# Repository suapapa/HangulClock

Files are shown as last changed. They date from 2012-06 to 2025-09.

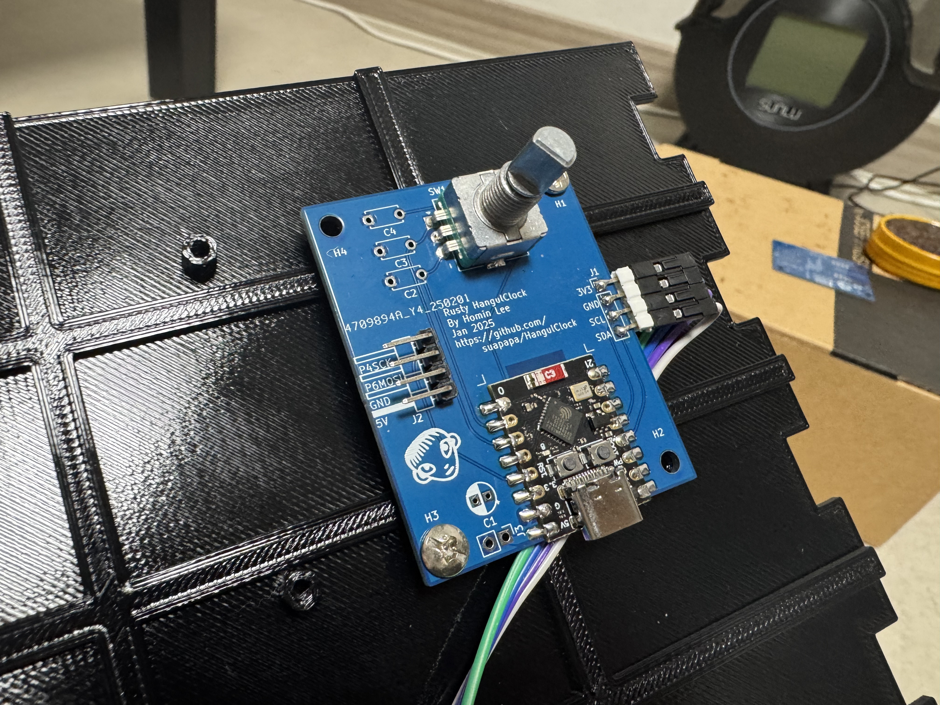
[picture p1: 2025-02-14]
rusty_hangulclock/photo/IMG_3785.jpg

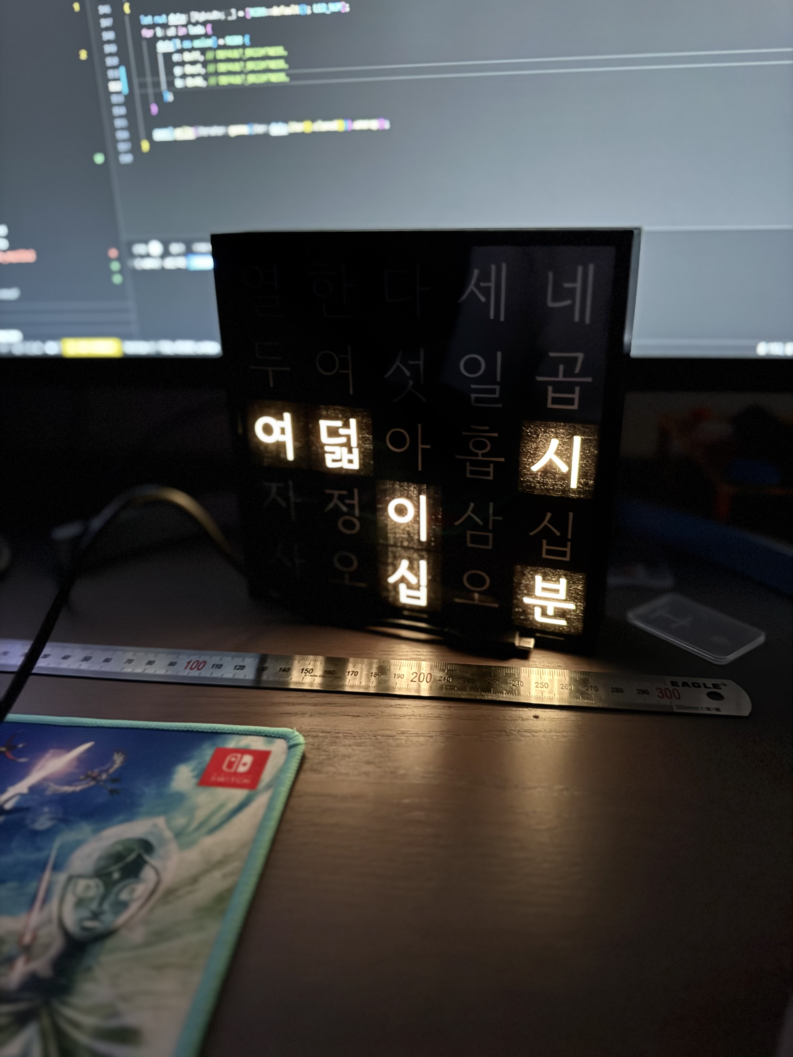
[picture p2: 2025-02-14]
rusty_hangulclock/photo/IMG_3756.jpg

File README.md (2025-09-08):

# 한글시계 - HangulClock

HangulClock

한글시계는 오픈소스(SW/HW) 입니다. [시연 동영상](https://youtu.be/ApymC7qAVTI)

- Make Korea의 2011 컨테스트 수상 작 (1등 없는 2등)
- [A Word Clock by drj113](http://www.instructables.com/id/A-Word-Clock/)에서 영감을 얻었습니다.

## 소스코드

### Rusty HangulClock

~~Please Refer [rusty_hangulclock/README.md](rusty_hangulclock/README.md)~~

> ⚠️ Moved to seperated repository [suapapa/rusty-hangulclock](https://github.com/suapapa/rusty-hangulclock)

### Go program which using Periph.io

Build for ARM64 SBCs:

    $ cd go_hangulclock
    $ GOARCH=arm64 GOOS=linux go build

Then, install binary and system service config by reference `deploy.sh`

### Arduino Sketch (prototype)

Need update submoduls HT1380 and LedControl to build the sketch;

    $ git submodule update

## 링크

- 블로그 글:
  - [다시만든 한글시계 with 러스트](https://homin.dev/blog/post/20241222_rusty_hangulclock/) - 2024-12
  - [11년 만에 완성한, 원조, 한글시계](https://homin.dev/blog/post/20221009_hangulclock_is_re-written_in_golang/) - 2022-09
  - [한글시계 뒷 이야기](https://homin.dev/blog/p=493/) - 2011-11

## 라이선스

### 5x5 한글 조합 - BY-CC

<br />이 저작물은 <a rel="license" href="http://creativecommons.org/licenses/by/4.0/">크리에이티브 커먼즈 저작자표시 4.0 국제 라이선스</a>에 따라 이용할 수 있습니다.

### 소스코드 - OpenSource

아두이노 스케치와, 고 프로그램의 라이선스가 각각 다릅니다. 각각의 폴더에서 확인하세요.
- Rust program: [rusty_hangulclock/LICENSE](rusty_hangulclock/LICENSE) - BSD
- Go program: [go_hangulclock/LICENSE](go_hangulclock/LICENSE) - BSD
- Arduino Sketch: [ardino/HangulClock/LICENSE](arduino/HangulClock/LICENSE) - GPL

### 회로도, 아트워크, 케이스 및 그 밖의 파일들 - Proprietary

회로도, 아트워크, 케이스 설계 파일 및 그 밖의 모든 파일들은 독점 라이선스 하에 있습니다. 
이러한 파일들의 사용, 복제, 수정, 배포는 저작권자의 명시적 허가 없이는 금지됩니다.

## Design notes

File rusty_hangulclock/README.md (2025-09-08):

# Rusty HangulClock

rusty_hangulclock

HangulClock written in Rust on ESP32C3 board

Hardware:
- [sch & pcb artwork](../sch/rusty-hangulclock/) - a KiCad project
- [case 3d model](../case/)

## Build and flash

### Pre requirement
Install toolchain (only for one time):
```sh
cargo install espup cargo-espflash ldproxy
espup install
```

### Build and flash:
For dotstar:
```sh
make flash_dotstar
```

For neopixel:
```sh
make flash_neopixel
```

### Factory reset settings:
```sh
make erase_nvs
```

## TODOs
- [x] Display color setting
- [x] Timezone setting
- [x] WPS to connect Wifi
- [x] NTP to sync time

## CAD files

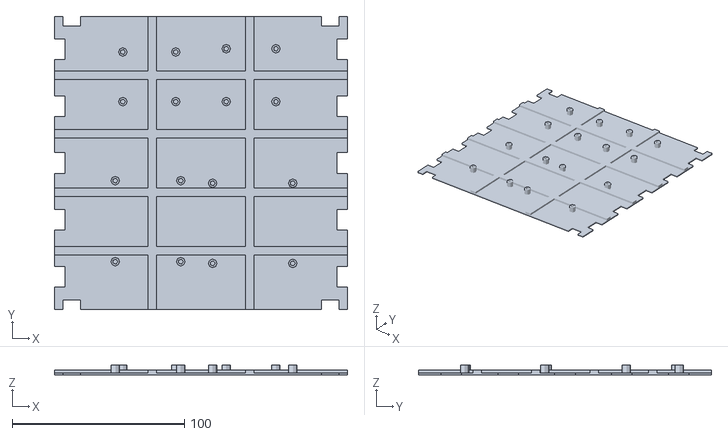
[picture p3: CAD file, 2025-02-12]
case/hangulclock_light_pannel.stl
170.0 x 170.0 x 5.60

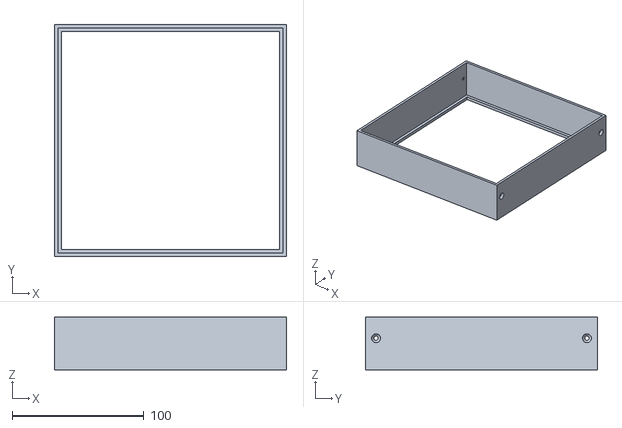
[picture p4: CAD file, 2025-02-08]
case/hangulclock_case.stl
176.0 x 176.0 x 40.0

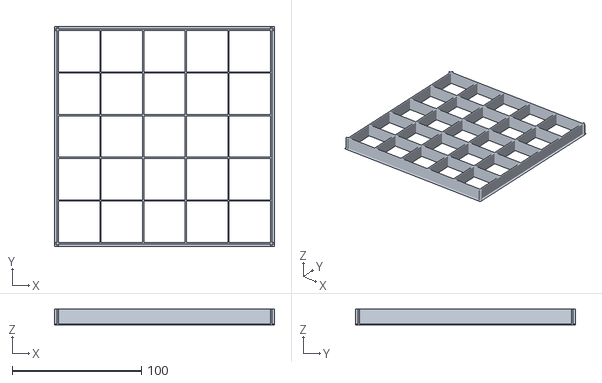
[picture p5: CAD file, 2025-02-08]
case/hangulclock_light_tunnel.stl
170.0 x 170.0 x 12.0

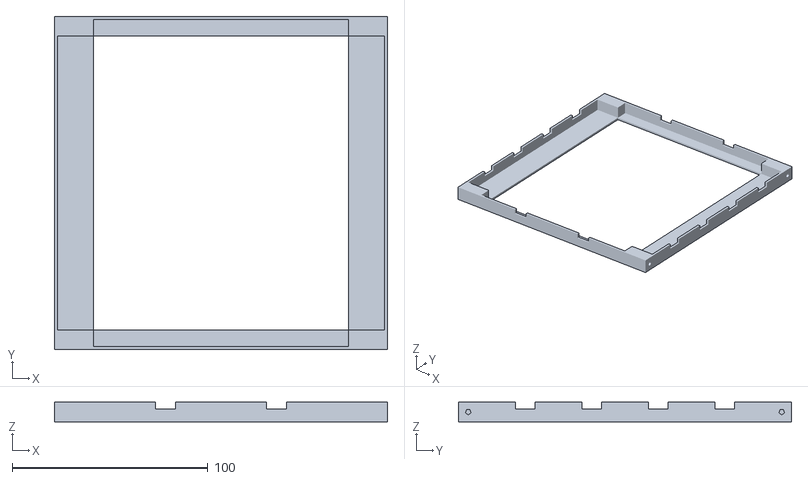
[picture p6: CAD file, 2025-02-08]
case/hangulclock_case_back.stl
170.0 x 170.0 x 10.0

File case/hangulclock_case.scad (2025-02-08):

difference() {
    translate([0,0,40/2])
        difference() {
            cube([176,176,40], center=true);
            cube([165,165,70], center=true);
            translate([0,0,3]) cube([171,171,40], center=true);
            //translate([2.5,2.5,2.5]) cube([170,170,70]);
            
        }

    translate([-170/2,170/2-5,24])
        rotate([0,90,0]) screw_hole();
    translate([-170/2,-170/2+5,24])
        rotate([0,90,0]) screw_hole();
    translate([170/2,170/2-5,24])
        rotate([0,-90,0]) screw_hole();
    translate([170/2,-170/2+5,24])
        rotate([0,-90,0]) screw_hole();
}



module screw_hole() {
    translate([0,0,-3])
    union() {
        translate([0,0,5]) cylinder(10, 1.5+0.1, 1.5+0.1, center=true, $fn=20);
        translate([0,0,2.5/2-0.2]) cylinder(2.5+0.1,3.5+0.1,1.5, center=true, $fn=20);
    }
}

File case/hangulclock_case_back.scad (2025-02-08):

difference() {
    cube([170,170,10], center=true);
    translate([0,0,1.6]) cube([170-1.6*2,150,10], center=true);
    translate([0,0,1.6]) cube([130,170-1.6*2,10], center=true);
    translate([0,0,0]) cube([130,150,15], center=true);
    
    translate([0,17,4]) cube([171,10,5], center=true);
    translate([0,17+34,4]) cube([171,10,5], center=true);
    translate([0,-17,4]) cube([171,10,5], center=true);
    translate([0,-17-34,4]) cube([171,10,5], center=true);
    translate([170/6,0,4]) cube([10,171,5], center=true);
    translate([-170/6,0,4]) cube([10,171,5], center=true);
    
    translate([-170/2,170/2-5,0])
        rotate([0,90,0]) cylinder(h=20,r=1.5,center=true);
    translate([-170/2,-170/2+5,0])
        rotate([0,90,0]) cylinder(h=20,r=1.5,center=true);
    translate([170/2,170/2-5,0])
        rotate([0,90,0]) cylinder(h=20,r=1.5,center=true);
    translate([170/2,-170/2+5,0])
        rotate([0,90,0]) cylinder(h=20,r=1.5,center=true);
}

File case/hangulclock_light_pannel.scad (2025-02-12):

difference() {
    union() {
        translate([-30,50,0]) oled_supports();
        translate([30,50,0]) oled_supports_v();
        translate([-30,-35,0]) board_supports();
        translate([30,-35,0]) board_supports_2();
        cube([170, 170, 1.2], center=true);
        translate([-170/6,0,1]) cube([5,170, 2.5], center=true);
        translate([+170/6,0,1]) cube([5,170, 2.5], center=true);
        translate([0,17,1]) cube([170, 5, 2.5], center=true);
        translate([0,17+34,1]) cube([170, 5, 2.5], center=true);
        translate([0,-17,1]) cube([170, 5, 2.5], center=true);
        translate([0,-17-34,1]) cube([170, 5, 2.5], center=true);
    }
    translate([-170/2,0,-1]) cube([12,12,15], center=true);
    translate([170/2,0,-1]) cube([12,12,15], center=true);
    translate([-170/2,33,-1]) cube([12,12,15], center=true);
    translate([170/2,33,-1]) cube([12,12,15], center=true);
    translate([-170/2,-33,-1]) cube([12,12,15], center=true);
    translate([170/2,-33,-1]) cube([12,12,15], center=true);    
    translate([-170/2,33*2,-1]) cube([12,12,15], center=true);
    translate([170/2,33*2,-1]) cube([12,12,15], center=true);
    translate([-170/2,-33*2,-1]) cube([12,12,15], center=true);
    translate([170/2,-33*2,-1]) cube([12,12,15], center=true);
    
    translate([75,82.5,0]) cube([10,6,2], center=true);
    translate([-75,82.5,0]) cube([10,6,2], center=true);
    translate([75,-82.5,0]) cube([10,6,2], center=true);
    translate([-75,-82.5,0]) cube([10,6,2], center=true);
}

module oled_supports() {
    translate([-(33.7-3)/2,-(31.8-3)/2]) {
        support(3, 5);
        translate([33.7-3,0,0]) support(3, 5);
        translate([0,31.8-3,0]) support(3, 5);
        translate([33.7-3,31.8-3,0]) support(3, 5);
    }
}

module oled_supports_v() {
    translate([-(33.7-3)/2,-(31.8-3)/2]) {
        support(3, 5);
        translate([0,33.7-3,0]) support(3, 5);
        translate([31.8-3,0,0]) support(3, 5);
        translate([31.8-3,33.7-3,0]) support(3, 5);
    }
}

// for pcb rev2 and rev3
module board_supports() {
    translate([-(41.5-2)/2,-(46.5-2)/2]) {
        support(3, 5);
        translate([38,0,0]) support(3, 5);
        translate([0,47,0]) support(3, 5);
        translate([38,47,0]) support(3, 5);
    }
}

// for pcb rev1
module board_supports_2() {
    translate([-(46.5)/2,-(46.5)/2]) {
        support(3, 5);
        translate([46.5,0,0]) support(3, 5);
        translate([0,46.5,0]) support(3, 5);
        translate([46.5,46.5,0]) support(3, 5);
    }
}

module support(in, h) {
    translate([0,0,h/2]) difference() {
        cylinder(h, in/2+1,in/2+1, center=true);
        translate([0,0,-1]) cylinder(h+2, in/2, in/2, center=true);
    }
}

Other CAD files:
case/hangulclock_light_tunnel.scad
case/spring.scad

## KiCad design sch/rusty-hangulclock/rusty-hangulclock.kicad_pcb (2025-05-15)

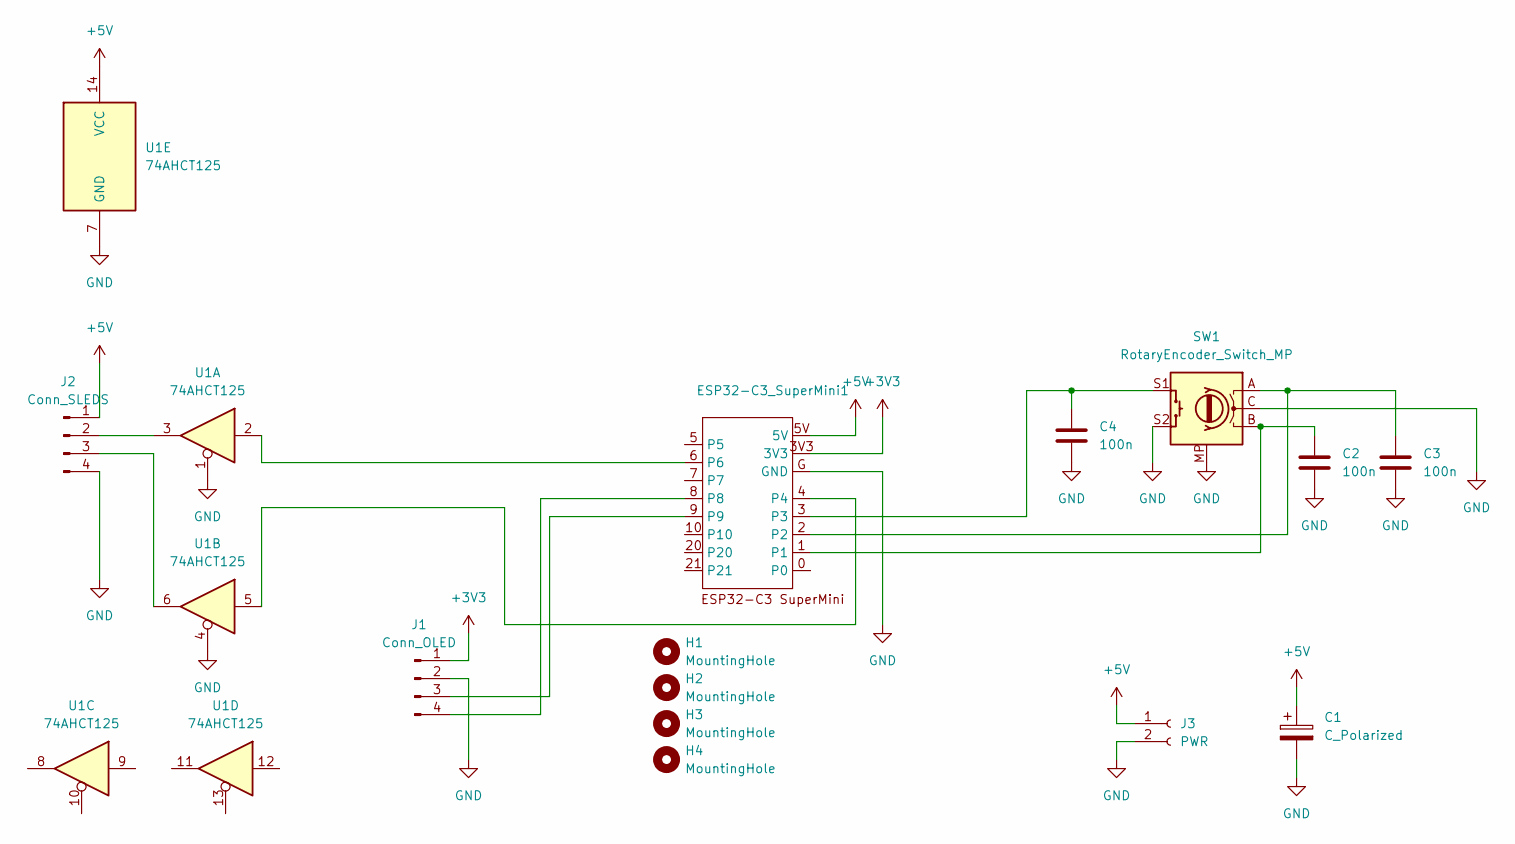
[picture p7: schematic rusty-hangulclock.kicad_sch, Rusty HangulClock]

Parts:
C1: C_Polarized; CP_Radial_D4.0mm_P2.00mm
C2, C3, C4: 100n; C_Disc_D5.0mm_W2.5mm_P5.00mm
ESP32-C3_SuperMini1: ESP32-C3_SuperMini_SMD
H1, H2, H3, H4: MountingHole; MountingHole_3.2mm_M3
J1: Conn_OLED; PinHeader_1x04_P2.54mm_Vertical
J2: Conn_SLEDS; PinHeader_1x04_P2.54mm_Horizontal
J3: PWR; PinHeader_1x02_P2.54mm_Vertical
SW1: RotaryEncoder_Switch_MP; RotaryEncoder_Alps_EC11E-Switch_Vertical_H20mm
U1: 74AHCT125; SOIC-14_3.9x8.7mm_P1.27mm

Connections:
+3V3: ESP32-C3_SuperMini1.3V3, J1.1
+5V: C1.1, ESP32-C3_SuperMini1.5V, J2.1, J3.1, U1.14 (VCC)
GND: C1.2, C2.2, C3.2, C4.2, ESP32-C3_SuperMini1.G (GND), J1.2, J2.4, J3.2, SW1.C, SW1.MP, SW1.S2, U1.1, U1.4, U1.7 (GND)
unnamed: C2.1, ESP32-C3_SuperMini1.1, SW1.B
unnamed: C3.1, ESP32-C3_SuperMini1.2, SW1.A
unnamed: C4.1, ESP32-C3_SuperMini1.3, SW1.S1
unnamed: ESP32-C3_SuperMini1.4, U1.5
unnamed: ESP32-C3_SuperMini1.6, U1.2
unnamed: ESP32-C3_SuperMini1.8, J1.4
unnamed: ESP32-C3_SuperMini1.9, J1.3
unnamed: J2.2, U1.3
unnamed: J2.3, U1.6

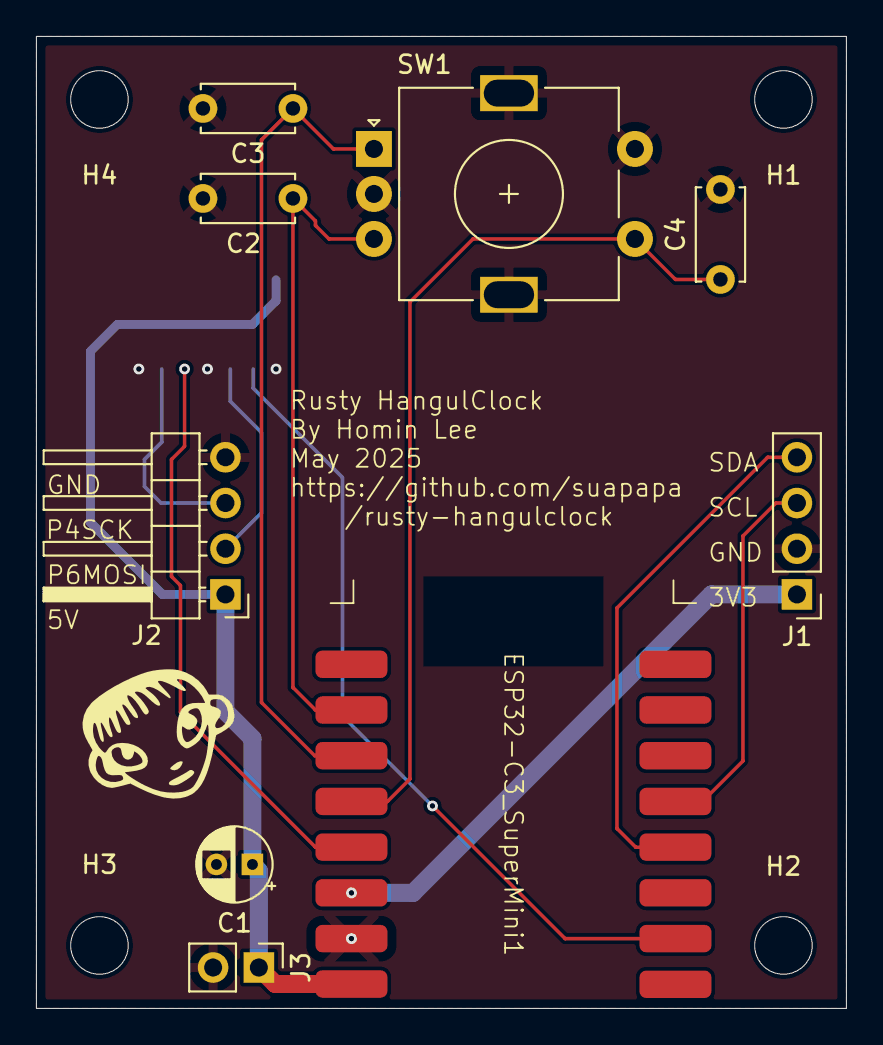
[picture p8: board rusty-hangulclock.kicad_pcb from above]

Board: 2 copper layers, 45.0 x 54.0 mm, 14 parts (1 on the bottom side), 12 nets.

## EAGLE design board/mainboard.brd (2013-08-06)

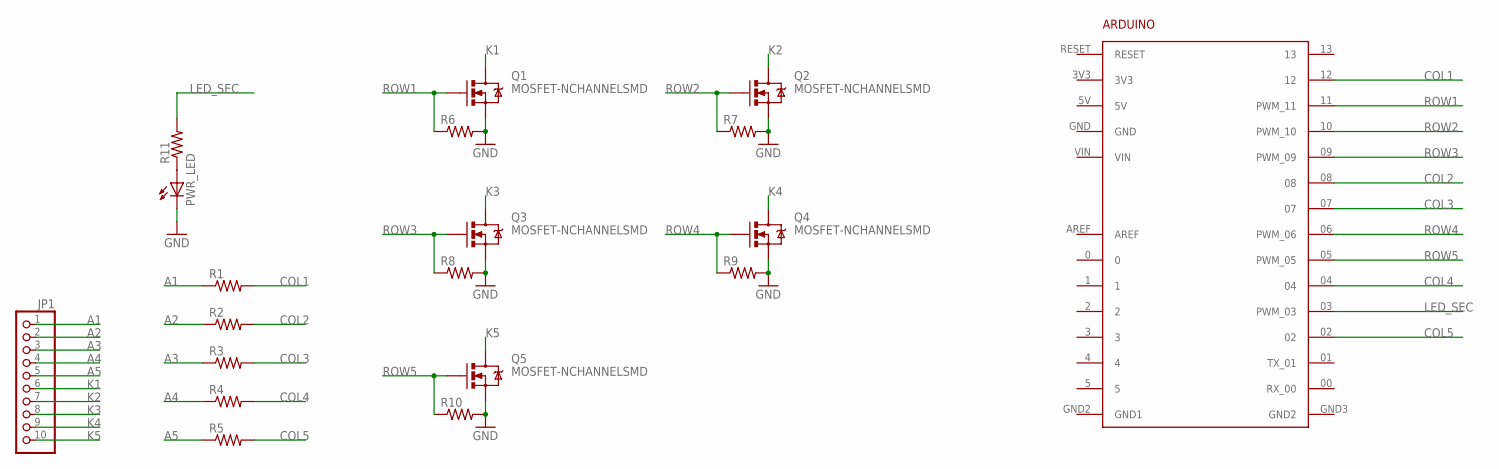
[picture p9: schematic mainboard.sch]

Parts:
ARDUINO1: ARDUINO
JP1: PINHD-1X10; 1X10
PWR_LED: LED5MM
Q1, Q2, Q3, Q4, Q5: MOSFET-NCHANNELSMD; SOT23-3
R1, R2, R3, R4, R5, R6, R7, R8, R9, R10, R11: R-US_M1206; M1206

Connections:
3V3: ARDUINO1.3V3
5V: ARDUINO1.5V
A1: JP1.1, R1.1
A2: JP1.2, R2.1
A3: JP1.3, R3.1
A4: JP1.4, R4.1
A5: JP1.5, R5.1
COL1: ARDUINO1.12, R1.2
COL2: ARDUINO1.08, R2.2
COL3: ARDUINO1.07, R3.2
COL4: ARDUINO1.04, R4.2
COL5: ARDUINO1.02, R5.2
GND: ARDUINO1.GND, PWR_LED.K (C), Q1.2 (S), Q2.2 (S), Q3.2 (S), Q4.2 (S), Q5.2 (S), R6.2, R7.2, R8.2, R9.2, R10.2
GND1: ARDUINO1.GND2 (GND1)
GND2: ARDUINO1.GND3 (GND2)
K1: JP1.6, Q1.3 (D)
K2: JP1.7, Q2.3 (D)
K3: JP1.8, Q3.3 (D)
K4: JP1.9, Q4.3 (D)
K5: JP1.10, Q5.3 (D)
LED_SEC: ARDUINO1.03 (PWM_03), R11.2
unnamed: PWR_LED.A, R11.1
ROW1: ARDUINO1.11 (PWM_11), Q1.1 (G), R6.1
ROW2: ARDUINO1.10 (PWM_10), Q2.1 (G), R7.1
ROW3: ARDUINO1.09 (PWM_09), Q3.1 (G), R8.1
ROW4: ARDUINO1.06 (PWM_06), Q4.1 (G), R9.1
ROW5: ARDUINO1.05 (PWM_05), Q5.1 (G), R10.1
VIN: ARDUINO1.VIN

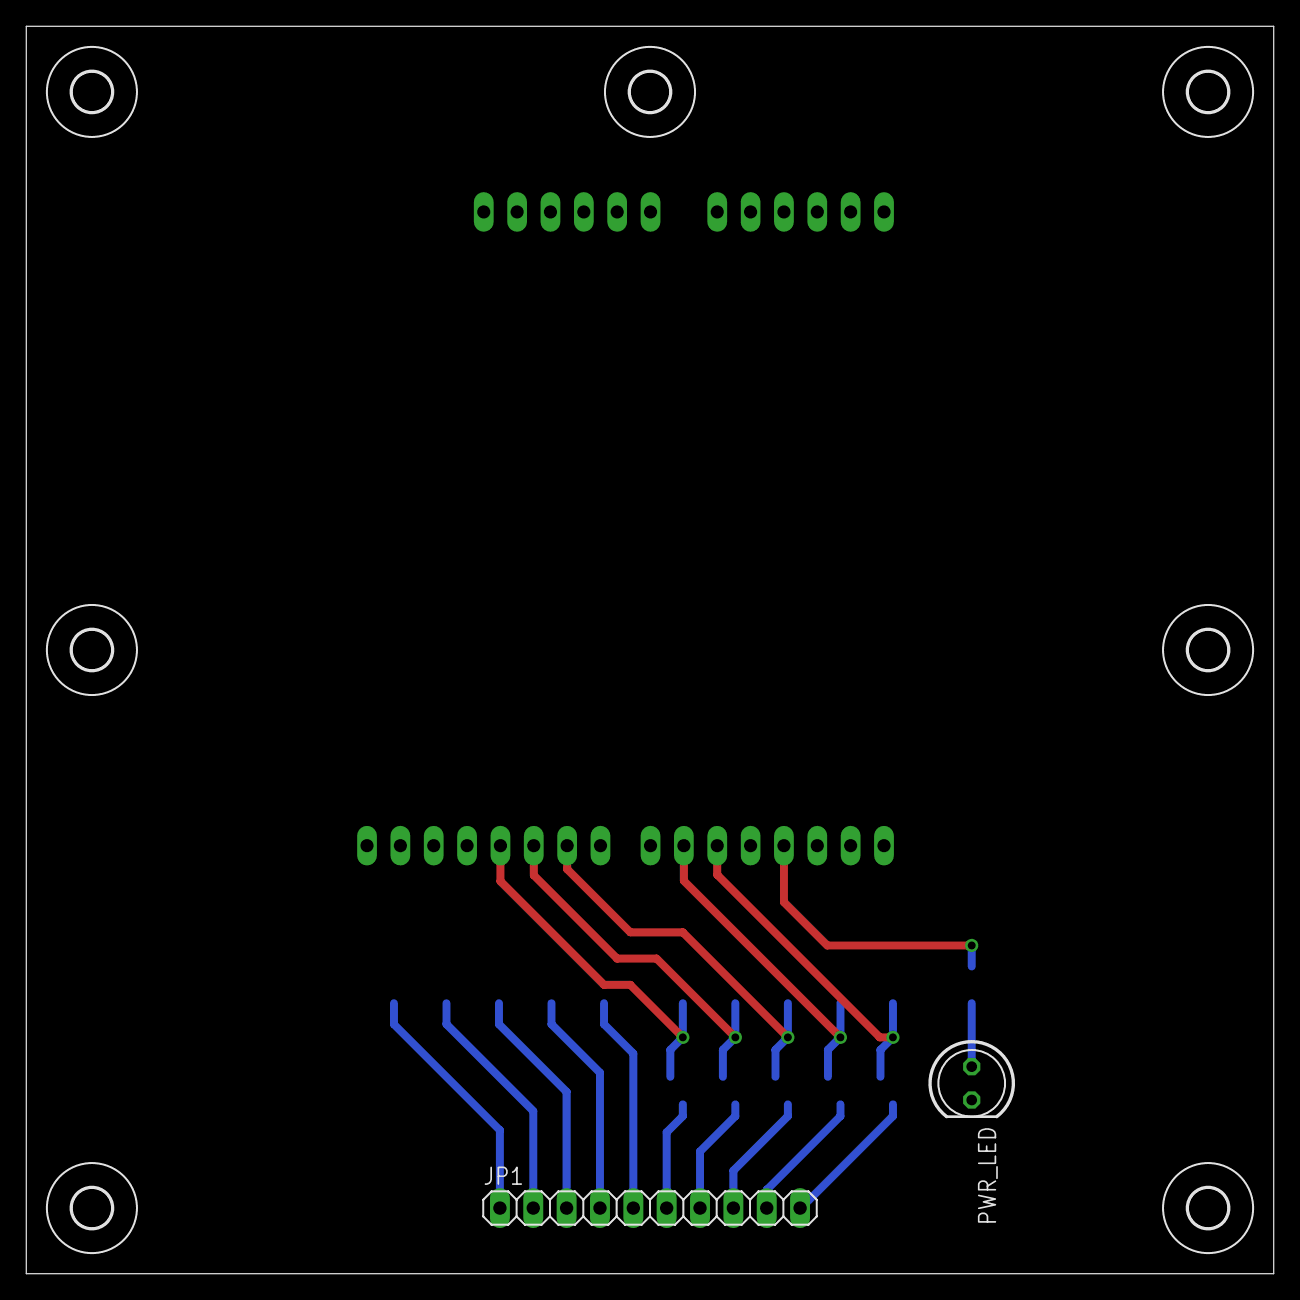
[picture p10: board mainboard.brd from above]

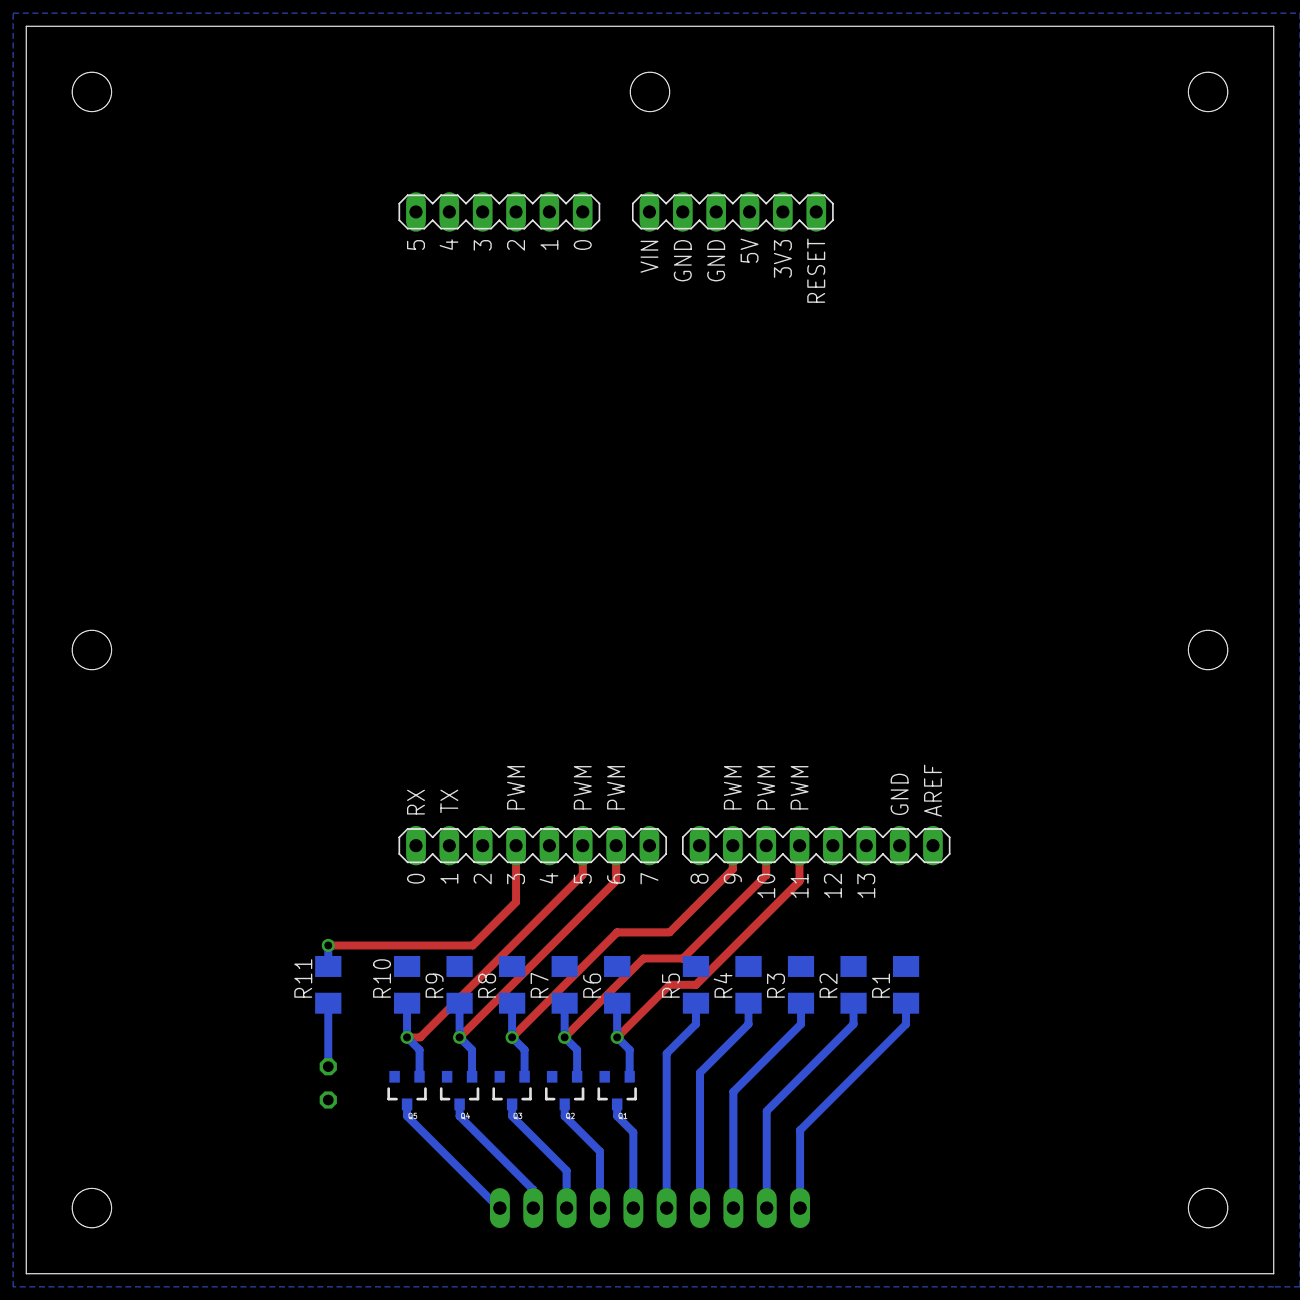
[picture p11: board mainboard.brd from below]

Board: 2 copper layers, 95.0 x 95.0 mm, 26 parts (17 on the bottom side), 23 nets.

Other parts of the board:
U$1, U$2, U$3, U$4, U$5, U$6, U$7: 3,0

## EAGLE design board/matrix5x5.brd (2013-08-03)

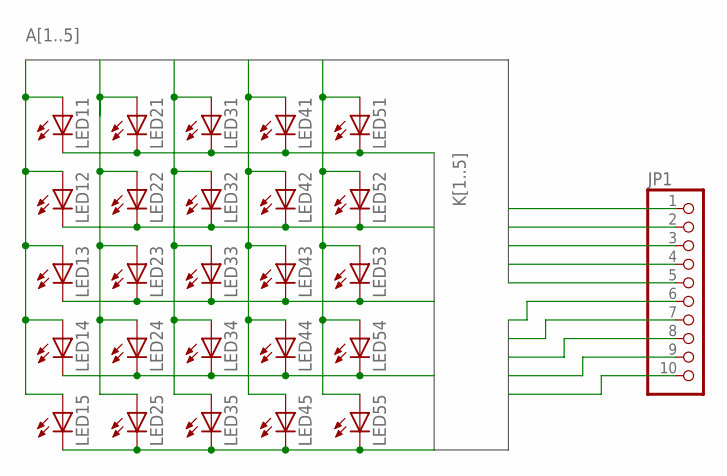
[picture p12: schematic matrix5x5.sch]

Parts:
JP1: PINHD-1X10; 1X10
LED11, LED12, LED13, LED14, LED15, LED21, LED22, LED23, LED24, LED25, LED31, LED32, LED33, LED34, LED35, LED41, LED42, LED43, LED44, LED45, LED51, LED52, LED53, LED54, LED55: LED5MM

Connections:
A1: JP1.1, LED11.A, LED12.A, LED13.A, LED14.A, LED15.A
A2: JP1.2, LED21.A, LED22.A, LED23.A, LED24.A, LED25.A
A3: JP1.3, LED31.A, LED32.A, LED33.A, LED34.A, LED35.A
A4: JP1.4, LED41.A, LED42.A, LED43.A, LED44.A, LED45.A
A5: JP1.5, LED51.A, LED52.A, LED53.A, LED54.A, LED55.A
K1: JP1.6, LED11.K (C), LED21.K (C), LED31.K (C), LED41.K (C), LED51.K (C)
K2: JP1.7, LED12.K (C), LED22.K (C), LED32.K (C), LED42.K (C), LED52.K (C)
K3: JP1.8, LED13.K (C), LED23.K (C), LED33.K (C), LED43.K (C), LED53.K (C)
K4: JP1.9, LED14.K (C), LED24.K (C), LED34.K (C), LED44.K (C), LED54.K (C)
K5: JP1.10, LED15.K (C), LED25.K (C), LED35.K (C), LED45.K (C), LED55.K (C)

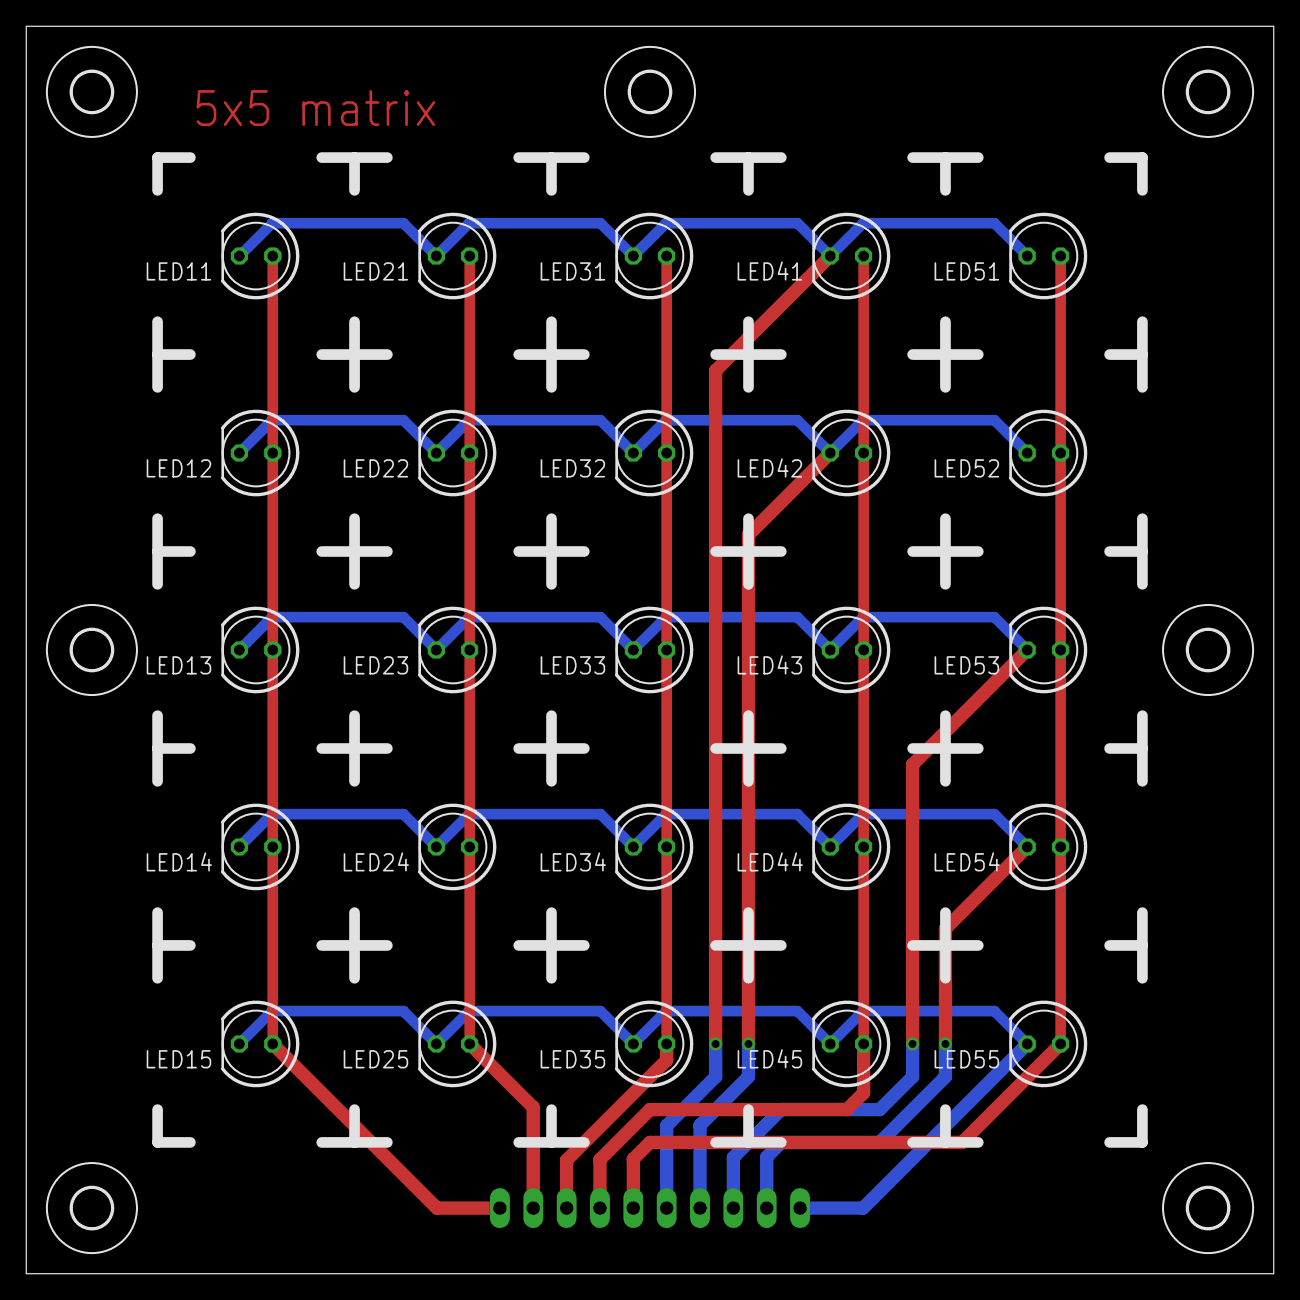
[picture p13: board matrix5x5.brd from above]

Board: 2 copper layers, 95.0 x 95.0 mm, 33 parts (1 on the bottom side), 10 nets.

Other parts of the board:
U$1, U$2, U$3, U$4, U$5, U$6, U$7: 3,0

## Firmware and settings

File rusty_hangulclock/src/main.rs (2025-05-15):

mod global;
mod menu;
mod net;
mod nvs;
mod panel;
mod rotary;

use chrono::prelude::*;
use embassy_time::{Duration, Timer};
// use embedded_hal::spi::MODE_3;
use esp_idf_svc::hal::gpio::*;
use esp_idf_svc::hal::i2c::*;
use esp_idf_svc::hal::peripherals::Peripherals;
use esp_idf_svc::hal::prelude::*;
use esp_idf_svc::hal::spi::{
    config::Config as SpiConfig, config::DriverConfig as SpiDriverConfig, SpiBusDriver, SpiDriver,
};
use esp_idf_svc::hal::task;
use esp_idf_svc::timer::EspTaskTimerService;
use esp_idf_svc::wifi::{AsyncWifi, EspWifi};
use esp_idf_svc::{eventloop::EspSystemEventLoop, nvs::EspDefaultNvsPartition};
use log::{info, warn};
use sh1106::{prelude::GraphicsMode as Sh1106GM, Builder as Sh1106Builder};
// use smart_leds::{gamma, hsv::hsv2rgb, hsv::Hsv, SmartLedsWrite, RGB8};
use std::time;

#[cfg(feature = "use_dotstar")]
use apa102_spi::MODE as SPI_MODE;
#[cfg(not(feature = "use_dotstar"))]
use ws2812_spi::MODE as SPI_MODE;

fn main() -> anyhow::Result<()> {
    esp_idf_svc::sys::link_patches();
    esp_idf_svc::log::EspLogger::initialize_default();
    info!("Hello, RustyHangulClock!");

    let p = Peripherals::take()?;

    let p_oled_sda = p.pins.gpio8;
    let p_oled_scl = p.pins.gpio9;
    // let p_oled_res = p.pins.gpio10;
    let p_sled_sclk = p.pins.gpio4;
    let p_sled_mosi = p.pins.gpio6;
    let p_sled_spi = p.spi2;
    let p_menu_r1 = p.pins.gpio1;
    let p_menu_r2 = p.pins.gpio2;
    let p_menu_sel = p.pins.gpio3;

    let mut menu_sel = PinDriver::input(p_menu_sel)?;
    menu_sel.set_pull(Pull::Up)?;

    let mut menu_r1 = PinDriver::input(p_menu_r1)?;
    menu_r1.set_pull(Pull::Up)?;
    let mut menu_r2 = PinDriver::input(p_menu_r2)?;
    menu_r2.set_pull(Pull::Up)?;

    // let mut disp_res = PinDriver::output(p_oled_res)?;
    // disp_res.set_low().unwrap();
    // std::thread::sleep(time::Duration::from_millis(100));
    // // Timer::after(Duration::from_millis(100)).await;
    // disp_res.set_high().unwrap();

    let i2c_config = I2cConfig::new().baudrate(50.kHz().into());
    let i2c = I2cDriver::new(
        p.i2c0,
        p_oled_sda, // SDA
        p_oled_scl, // SCL
        &i2c_config,
    )?;
    let mut disp: Sh1106GM<_> = Sh1106Builder::new().connect_i2c(i2c).into();
    disp.init().unwrap();
    // disp.set_rotation(sh1106::prelude::DisplayRotation::Rotate180).unwrap();
    disp.flush().unwrap();
    menu::draw_text(
        &mut disp,
        &format!("Rusty HangulClock\nno.6\ninitializing..."),
    )?;

    let mut spi_driver = SpiDriver::new(
        p_sled_spi,
        p_sled_sclk,
        p_sled_mosi,
        AnyIOPin::none(),
        &SpiDriverConfig::new(),
    )?;
    let spi_config = SpiConfig::new()
        .baudrate(3.MHz().into())
        .data_mode(SPI_MODE);
    let spi_bus = SpiBusDriver::new(&mut spi_driver, &spi_config)?;
    let mut sleds = panel::Sleds::new(spi_bus);
    sleds.welcome();
    let sys_loop = EspSystemEventLoop::take()?;
    let timer_service = EspTaskTimerService::new()?;
    let nvs = EspDefaultNvsPartition::take()?;
    let mut wifi = AsyncWifi::wrap(
        EspWifi::new(p.modem, sys_loop.clone(), Some(nvs))?,
        sys_loop,
        timer_service,
    )?;

    task::block_on(async {
        info!("initial time sync...");
        match net::sync_time_with_wifi(&mut wifi).await {
            Ok(_) => (),
            Err(e) => {
                warn!("Failed to sync time: {:?}", e);
            }
        }
    });

    let net_task = net::net_loop(&mut wifi);
    let show_time_task = show_time_loop(&mut sleds);
    let menu_task = menu::menu_loop(&mut disp, menu_sel);
    let time_sync_task = time_sync_loop();
    let rotary_encoder_task = rotary::rotary_encoder_loop(menu_r2, menu_r1);

    info!("Starting tasks...");
    task::block_on(async {
        match futures::try_join!(
            menu_task,
            net_task,
            time_sync_task,
            show_time_task,
            rotary_encoder_task
        ) {
            Ok(_) => info!("All tasks completed"),
            Err(e) => info!("Error in task: {:?}", e),
        }
    });

    Ok(())
}

async fn time_sync_loop() -> anyhow::Result<()> {
    info!("Starting time_sync_loop()...");

    loop {
        Timer::after(Duration::from_secs(60 * 60 * 24)).await; // 24 hours
        {
            match global::CMD_NET.try_lock() {
                Ok(mut cmd_net) => {
                    *cmd_net = "NTP".to_string();
                    info!("NTP cmd sent");
                }
                Err(_) => {
                    warn!("CMD_NET in use");
                }
            }
        }
    }
}

async fn show_time_loop<SPI>(sleds: &mut panel::Sleds<SPI>) -> anyhow::Result<()>
where
    SPI: embedded_hal::spi::SpiBus,
{
    info!("Starting show_time_loop()...");
    //sleds.turn_on_all();

    let mut skip_display: bool; // = false;
    let mut ntp_ok: bool; // = false;
    let mut last_h: u8 = 0;
    let mut last_m: u8 = 0;

    let utc_offset: i32 = nvs::get_utc_offset()?;

    loop {
        match global::IN_MENU.try_lock() {
            Ok(in_menu) => {
                skip_display = *in_menu;
            }
            Err(_) => {
                // warn!("IN_MENU in use");
                Timer::after(Duration::from_secs(1)).await;
                continue;
            }
        }

        if skip_display {
            sleds.turn_on_all();
            Timer::after(Duration::from_millis(500)).await;
            continue;
        }

        match global::TIME_SYNCED.try_lock() {
            Ok(time_synced) => {
                if !*time_synced {
                    match global::CMD_NET.try_lock() {
                        Ok(mut cmd_net) => {
                            *cmd_net = "NTP".to_string();
                            info!("NTP cmd sent");
                        }
                        Err(_) => {
                            info!("CMD_NET in use");
                            continue;
                        }
                    }
                    loop {
                        Timer::after(Duration::from_millis(1000)).await;
                        if let Ok(mut result) = global::RESULT_NET.try_lock() {
                            if result.as_str() == "OK" || result.as_str() == "NG" {
                                info!("NTP cmd completed: {}", result.as_str());
                                *result = "".to_string();
                                ntp_ok = result.as_str() == "OK";
                                break;
                            }
                        }
                    }
                } else {
                    ntp_ok = true;
                }
            }
            Err(_) => {
                warn!("TIME_SYNCED in use");
                continue;
            }
        }

        if !ntp_ok {
            Timer::after(Duration::from_secs(10)).await;
            continue;
        }

        let now = time::SystemTime::now();
        let timestamp = now.duration_since(time::UNIX_EPOCH).unwrap().as_millis();
        let datetime = Utc.timestamp_millis_opt(timestamp as i64).unwrap();
        let datetime_kst =
            datetime.with_timezone(&FixedOffset::east_opt(utc_offset * 3600).unwrap());
        // info!("Current datetime: {}", datetime_kst);

        let h: u8 = datetime_kst.hour() as u8;
        let m: u8 = datetime_kst.minute() as u8;
        if last_h != h || last_m != m {
            last_h = h;
            last_m = m;
            {
                // h, m 값을 전역 변수에 저장
                if let Ok(mut global_h) = global::CUR_H.try_lock() {
                    *global_h = h;
                }
                if let Ok(mut global_m) = global::CUR_M.try_lock() {
                    *global_m = m;
                }
            }
            info!("Time updated, h: {}, m: {}", h, m);
            sleds.show_time(h, m);
        }
        Timer::after(Duration::from_secs(1)).await;
    }
    // Ok(())
}

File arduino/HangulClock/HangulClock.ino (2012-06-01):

// MAX7219, matrix driver
#include <LedControl.h>

#define PIN_MAX7219_DATA 5//16 //4
#define PIN_MAX7219_CLK  6//15 //3
#define PIN_MAX7219_LOAD 7//14 //2
LedControl lc = LedControl(PIN_MAX7219_DATA,
                           PIN_MAX7219_CLK,
                           PIN_MAX7219_LOAD,
                           1);



byte panel[8] = {0, };

// Fix shuffled row and column idx.
#define R0 4
#define R1 6
#define R2 2
#define R3 3
#define R4 7
#define C0 6
#define C1 1
#define C2 5
#define C3 0
#define C4 4
byte r_table[5] = {R0, R1, R2, R3, R4};
byte c_table[5] = {C0, C1, C2, C3, C4};

#define _P_ON(_R, _C) panel[_R] |= (1 << _C)
#define P_ON(_R, _C) _P_ON(R##_R, C##_C)
#define REFRESH_PANEL() \
  for (int i = 0; i < 8; i++) \
    lc.setRow(0, i, panel[i])

#define CLEAN_PANEL() \
  lc.clearDisplay(0); \
  memset(panel, 0x00, 8)


#ifdef USE_HT1380_RTC
// HT1380, RTC
#include <HT1380.h>
//HT1380 rtc = HT1380(7, 6, 5);
HT1380 rtc = HT1380(19, 18, 17);
#else
unsigned long last_rtc_millis;
void update_dummy_rtc(void);
#endif


uint8_t curr_h, curr_m, curr_s;
void set_rtc(uint8_t, uint8_t, uint8_t);
void get_rtc(void);

unsigned long last_millis;
void show_time(int, int);
#define SHOW_CURR_TIME() show_time(curr_h, curr_m)


#define PIN_LED 13

void demo(void);
void splash(void);
void init_ips(void)
{
    Serial.println("Initing matrix driver...");
    lc.shutdown(0, false);
    lc.setIntensity(0, 15);
    lc.clearDisplay(0);

#ifdef USE_HT1380_RTC
    Serial.println("Initing RTC...");
    rtc.init();
#endif
}

void setup(void)
{
    pinMode(PIN_LED, OUTPUT);
    digitalWrite(PIN_LED, HIGH);

    Serial.begin(9600);
    init_ips();
    splash();
    last_millis = millis();
#ifndef USE_HT1380_RTC
    set_rtc(10, 32, 45);
#endif
    get_rtc();
    SHOW_CURR_TIME();

    digitalWrite(PIN_LED, LOW);
    Serial.println("HELLO");
}

bool tick_tock = LOW;
void loop(void)
{
    unsigned long curr_millis = millis();


#ifndef USE_HT1380_RTC
    if ((curr_millis - last_rtc_millis) >= 1000) {
        update_dummy_rtc();
        last_rtc_millis = curr_millis;
        tick_tock = (tick_tock == HIGH ? LOW : HIGH);
        digitalWrite(PIN_LED, tick_tock);
    }
#endif

    // update panel in every 1 min
    if ((curr_millis - last_millis) >= 5 * 1000) {
        get_rtc();
        SHOW_CURR_TIME();
        last_millis = curr_millis;
    }

    // Serial commands
    // #D for Demo
    // #L<r><c> for turn on a LED in row r and column c
    // #S<hh><mm><ss> set time
    // #G get time
    if (Serial.available() > 1 && '#' == Serial.read()) {
        char func = Serial.read();
        int hour = 0;
        int minute = 0;
        int sec = 0;
        delay(10); // wait enough for following chars
        if (func == 'D') {          // Demo
            demo();
        } else if (func == 'G') {   // Get time
            get_rtc();
            Serial.print((int)(curr_h));
            Serial.print(":");
            Serial.print((int)(curr_m));
            Serial.print(":");
            Serial.print((int)(curr_s));
        } else if (func == 'S') {   // Set time
            hour = 10 * (Serial.read() - '0');
            hour += (Serial.read() - '0');
            minute = 10 * (Serial.read() - '0');
            minute += (Serial.read() - '0');
            sec = 10 * (Serial.read() - '0');
            sec += (Serial.read() - '0');
            set_rtc((uint8_t)hour, (uint8_t)minute, (uint8_t)sec);
            get_rtc();
            SHOW_CURR_TIME();
            last_millis = millis();
        } else if (func == 'L') {
            byte r = Serial.read() - '0';
            byte c = Serial.read() - '0';

            CLEAN_PANEL();
            _P_ON(r_table[r], c_table[c]);
            REFRESH_PANEL();
        }
        Serial.println("OK");
    }

    delay(100); // sleep 100ms
}

int last_shown_h = -1;
int last_shown_m = -1;
void show_time(int h, int m)
{
#if 0
    Serial.print("show_time: ");
    Serial.print(h);
    Serial.print(":");
    Serial.println(m);
#endif

    if (h == last_shown_h && m == last_shown_m)
        return;

    // update current time from RTC in every hour
    if (h != last_shown_h)
        get_rtc();

    last_shown_h = h;
    last_shown_m = m;

    int m_10 = m / 10;
    int m_1 = m % 10;

    switch (m_1) {
    case 1 ... 3:
        m_1 = 0;
        break;
    case 4 ... 6:
        m_1 = 5;
        break;
    case 7 ... 9:
        m_1 = 0;
        m_10 += 1;
        break;
    }

    if (m_10 >= 6) {
        m_10 = 0;
        h += 1;
    }

    CLEAN_PANEL();

    if ((h == 0 || h == 24) && (m_10 + m_1) == 0) {
        P_ON(3, 0); P_ON(3, 1);
        return;
    }

    if (h == 12 && (m_10 + m_1) == 0) {
        P_ON(3, 1); P_ON(4, 1);
        return;
    }

    if (h > 12) h -= 12;
    switch (h) {
    case 0:
    case 12:
        P_ON(0, 0); P_ON(1, 0); P_ON(2, 4);
        break;
    case 1:
        P_ON(0, 1); P_ON(2, 4);
        break;
    case 2:
        P_ON(1, 0); P_ON(2, 4);
        break;
    case 3:
        P_ON(0, 3); P_ON(2, 4);
        break;
    case 4:
        P_ON(0, 4); P_ON(2, 4);
        break;
    case 5:
        P_ON(0, 2); P_ON(1, 2); P_ON(2, 4);
        break;
    case 6:
        P_ON(1, 1); P_ON(1, 2); P_ON(2, 4);
        break;
    case 7:
        P_ON(1, 3); P_ON(1, 4); P_ON(2, 4);
        break;
    case 8:
        P_ON(2, 0); P_ON(2, 1); P_ON(2, 4);
        break;
    case 9:
        P_ON(2, 2); P_ON(2, 3); P_ON(2, 4);
        break;
    case 10:
        P_ON(0, 0); P_ON(2, 4);
        break;
    case 11:
        P_ON(0, 0); P_ON(0, 1); P_ON(2, 4);
        break;
    }

    if (m == 0) {
        REFRESH_PANEL();
        return;
    }

    switch (m_10) {
    case 1:
        P_ON(3, 4); P_ON(4, 4);
        break;
    case 2:
        P_ON(3, 2); P_ON(4, 2); P_ON(4, 4);
        break;
    case 3:
        P_ON(3, 3); P_ON(3, 4); P_ON(4, 4);
        break;
    case 4:
        P_ON(4, 0); P_ON(4, 2); P_ON(4, 4);
        break;
    case 5:
        P_ON(4, 1); P_ON(4, 2); P_ON(4, 4);
        break;
    }

    if (m_1 == 5) {
        P_ON(4, 3); P_ON(4, 4);
    }

    REFRESH_PANEL();
}

void splash(void)
{
    for (int r = 0; r < 5; r++) {
        for (int c = 0; c < 5; c++) {
            CLEAN_PANEL();
            _P_ON(r_table[r], c_table[c]);
            REFRESH_PANEL();
            delay(50);
        }
    }
    CLEAN_PANEL();
}

void demo(void)
{
    for (int h = 0; h < 24; h++) {
        for (int m = 0; m < 60; m += 5) {
            digitalWrite(PIN_LED, HIGH);
            show_time(h, m);
            digitalWrite(PIN_LED, LOW);
            delay(500); // 1sec
        }
    }
    CLEAN_PANEL();
}

#ifdef USE_HT1380_RTC
void set_rtc(uint8_t h, uint8_t m, uint8_t s)
{
    rtc.setHour(h);
    rtc.setMin(m);
    rtc.setSec(s);
#if 0
    rtc.setYear(8);
    rtc.setMonth(8);
    rtc.setDate(19);
    rtc.setDay(3);
    rtc.setWP(1);
    delay(1000);
#endif
    rtc.writeBurst();
    delay(1000);
}
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

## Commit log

2011-03-29 arduino: added skel sketch from arscons, http://code.google.com/p/arscons/
2011-03-29 arduino: added code for basic test for matrix
2011-03-30 arduino: replaced more good looking mat test.
2011-05-17 tools: script for making silkscreen of panel
2011-06-10 arduino: added brightness control
2011-06-14 arduino: added codes for turn on leds for given H and M
2011-06-14 arduino: added library for RTC, HT1380
2011-06-14 arduino: added func for set RTC
2011-06-14 arduino: Added serial command for funcs of the clock
2011-06-26 arduino: Rotated matrix, more test with serial command
2011-06-28 arduino: round up minute in step 5
2011-06-28 board: added eaglecad schs
    [matrix5x5.sch, matrixDriver.sch]
2011-06-29 arduino: cleaned code
2011-06-29 arduino: removed rtc codes
2011-06-30 arduino: fixed bug on show_time()
2011-07-20 arduino: fixed to update current time in every sec
2011-07-20 arduino: added RTC, HT1380
2011-07-27 arduino: fixed to using ATmega8L, 8MHz
    you should add new board to;
    /usr/share/arduino/hardware/arduino/boards.txt
    add new board atmega8l like this;
    atmega8l.name=Arduino8L 8MHz
    atmega8l.upload.protocol=arduino
    atmega8l.upload.maximum_size=7168
    atmega8l.upload.speed=19200
    atmega8l.bootloader.low_fuses=0xd4
    atmega8l.bootloader.high_fuses=0xca
    atmega8l.bootloader.path=atmega8
    atmega8l.bootloader.file=ATmegaBOOTL.hex
    atmega8l.bootloader.unlock_bits=0x3F
    atmega8l.bootloader.lock_bits=0x0F
    atmega8l.build.mcu=atmega8
    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
2012-06-01 Porting to Arduino 1.0.x
2012-06-01 arduino fixed sketch works with Arduino 1.x
    [HangulClock.ino]
2012-06-01 update the clock in every 5 secs
    1min seems too long. no update happened.
    [HangulClock.ino]
2013-07-29 board: add artwork for sketch
    [matrix5x5.brd, matrix5x5.sch]
2013-08-02 board: fix net name and add artwork
    [matrix5x5.brd, matrix5x5.sch]
2013-08-03 board: add more holes to matrix board
    [matrix5x5.brd]
2013-08-04 board: adding main board
    [mainboard.brd, mainboard.sch]
2013-08-05 board: add more components into mainboard
    [mainboard.brd, mainboard.sch]
2013-08-06 board: add arduino to mainboard
    [mainboard.brd, mainboard.sch]
2018-12-13 README.md: 여러분들의 한글시계 사이트 등록
2024-12-19 fix font to 소요단풍체
2024-12-19 rust: add dotstar led strip
2024-12-19 add files for case
    [hangulclock_case.scad, hangulclock_case.stl, hangulclock_light_pannel.scad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]
2024-12-21 fix case size
    [hangulclock_case.scad, hangulclock_case.stl]
2024-12-21 case: add back
    [hangulclock_case_back.scad, hangulclock_case_back.stl]
2024-12-23 finetune case
    [hangulclock_light_pannel.scad, hangulclock_light_pannel.stl, hangulclock_light_tunnel.scad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]
2024-12-30 fix case back
    [hangulclock_case_back.scad, hangulclock_case_back.stl]
2024-12-31 light panel
    [hangulclock_light_pannel.scad, hangulclock_light_pannel.stl]
2025-01-01 add kicad sch and gerber
    [rusty-hangulclock.kicad_pcb, rusty-hangulclock.kicad_sch]
2025-01-01 sch: pcb round routes
    [rusty-hangulclock.kicad_pcb]
2025-01-03 fix dimention
    [hangulclock_light_pannel.scad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]
2025-01-04 fix sch and pcb
    [rusty-hangulclock.kicad_pcb, rusty-hangulclock.kicad_sch]
2025-01-14 rusty_hangulclock: change mcu to esp32c3
2025-01-15 split code to files
    [rusty-hangulclock.kicad_pcb, rusty-hangulclock.kicad_sch]
2025-01-26 use nvs to store wifi cred
    [part.csv]
2025-01-28 set wifi tx power for esp32c3-supermini
2025-01-31 sch: re-draw sch and artwork for v1.0.0
    [rusty-hangulclock.kicad_pcb, rusty-hangulclock.kicad_sch]
2025-02-02 sch: fix pcb
    [rusty-hangulclock.kicad_pcb]
2025-02-02 fix pcb
    [rusty-hangulclock.kicad_pcb]
2025-02-03 update sch and gerber
    [rusty-hangulclock-B_Cu.gbr, rusty-hangulclock-B_Mask.gbr, rusty-hangulclock-B_Paste.gbr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]
2025-02-08 case: fix case to reduce print time
    [hangulclock_case.scad, hangulclock_case.stl, hangulclock_case_back.scad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]
2025-02-12 case: update case
    [hangulclock_light_pannel.scad, hangulclock_light_pannel.stl, spring.scad]
2025-05-11 rusty_hangulclock: add rotary encoder test code
2025-05-11 fix(rusty-hangulclock): fix burst input
    [main.rs]
2025-05-11 feat(rusty-hangulclock): implement rotary encoder event handling
2025-05-11 refactor(rusty-hangulclock): move rotary encoder logic to separate module
2025-05-12 feat(rusty-hangulclock): add CUR_H and CUR_M mutexes for current time tracking and update menu display with time
2025-05-12 feat(rusty-hangulclock): add LED color settings to menu and global state management
2025-05-12 feat(rusty-hangulclock): integrate HSV settings storage and retrieval with NVS for LED color management
2025-05-13 feat(rusty-hangulclock): update initialization message and add turn_on_all method for LED control
2025-05-15 feat: rev7.
    [rusty-hangulclock.kicad_pcb, rusty-hangulclock.kicad_sch]

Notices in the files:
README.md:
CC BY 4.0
